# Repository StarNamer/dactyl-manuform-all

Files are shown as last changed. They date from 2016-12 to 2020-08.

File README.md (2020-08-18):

<div align="center">

# Dactyl ManuForm Keyboard



This is a fork of the [Dactyl-ManuForm](https://github.com/tshort/dactyl-keyboard).  
The Dactyl-Manuform is a fork of the [Dactyl](https://github.com/adereth/dactyl-keyboard) with the thumb cluster from [ManuForm](https://github.com/jeffgran/ManuForm).

</div>

## Differences to [carbonfet's](https://github.com/carbonfet/dactyl-manuform) dactyl-manuform
This version is adapted to my preferences and requirements. As such, there are a number of changes made to the root projects; the keyboard is still customizable, but changing the variables/parameters may require code changes as well.  
Changes to root project:

- Inclusion of [crystalhand's](https://github.com/crystalhand/dactyl-keyboard) wrist-rest
- All 1.0u keys (most ortho kits should provide all caps required for this build)
- Default manuform thumb cluster, but moved out a little bit (I have big hands and want my thumb to rest on the first thumb key)
- Some fixes to the generated bottom plate, which was faulty if extra bottom row is used (which I do)
- Usage of Bossard BN1936 brass inserts (M3) for screws
- Screw nubs moved inside the case

## Future changes (planned)

- Removal of controller board / TRRS jack holder breakout and putting of USB-C jack instead
- Development of my own controller board, QMK (and maybe VIA) programmable
- (Hopefully) Usage of BLE (as two separate keyboards) so no connection between the halves required
- (Alternatively) Usage of higher-quality 5-pin jack (no TRRS or audio jacks)

## Generate OpenSCAD and STL models

* Run `lein generate` or `lein auto generate`
* This will regenerate the `things/*.scad` files
* Use OpenSCAD to open a `.scad` file.
* Make changes to design, repeat `load-file`, OpenSCAD will watch for changes and rerender.
* When done, use OpenSCAD to export STL files

## License

Copyright © 2015-2020 Matthew Adereth, Tom Short and Leo Lou, Andreas Hauser

The source code for generating the models is distributed under the [GNU AFFERO GENERAL PUBLIC LICENSE Version 3](LICENSE).

The generated models are distributed under the [Creative Commons Attribution-ShareAlike 4.0 International (CC BY-SA 4.0)](LICENSE-models).

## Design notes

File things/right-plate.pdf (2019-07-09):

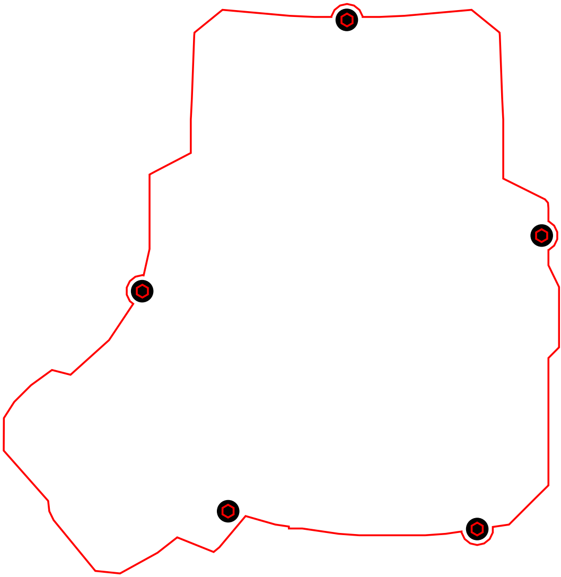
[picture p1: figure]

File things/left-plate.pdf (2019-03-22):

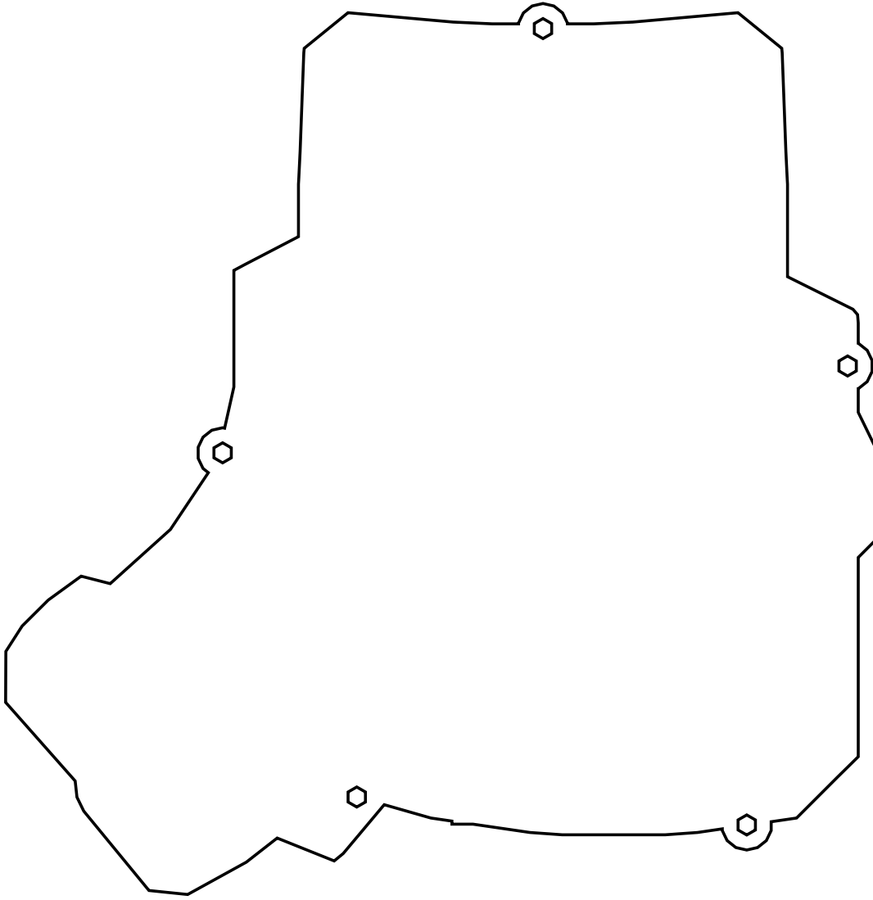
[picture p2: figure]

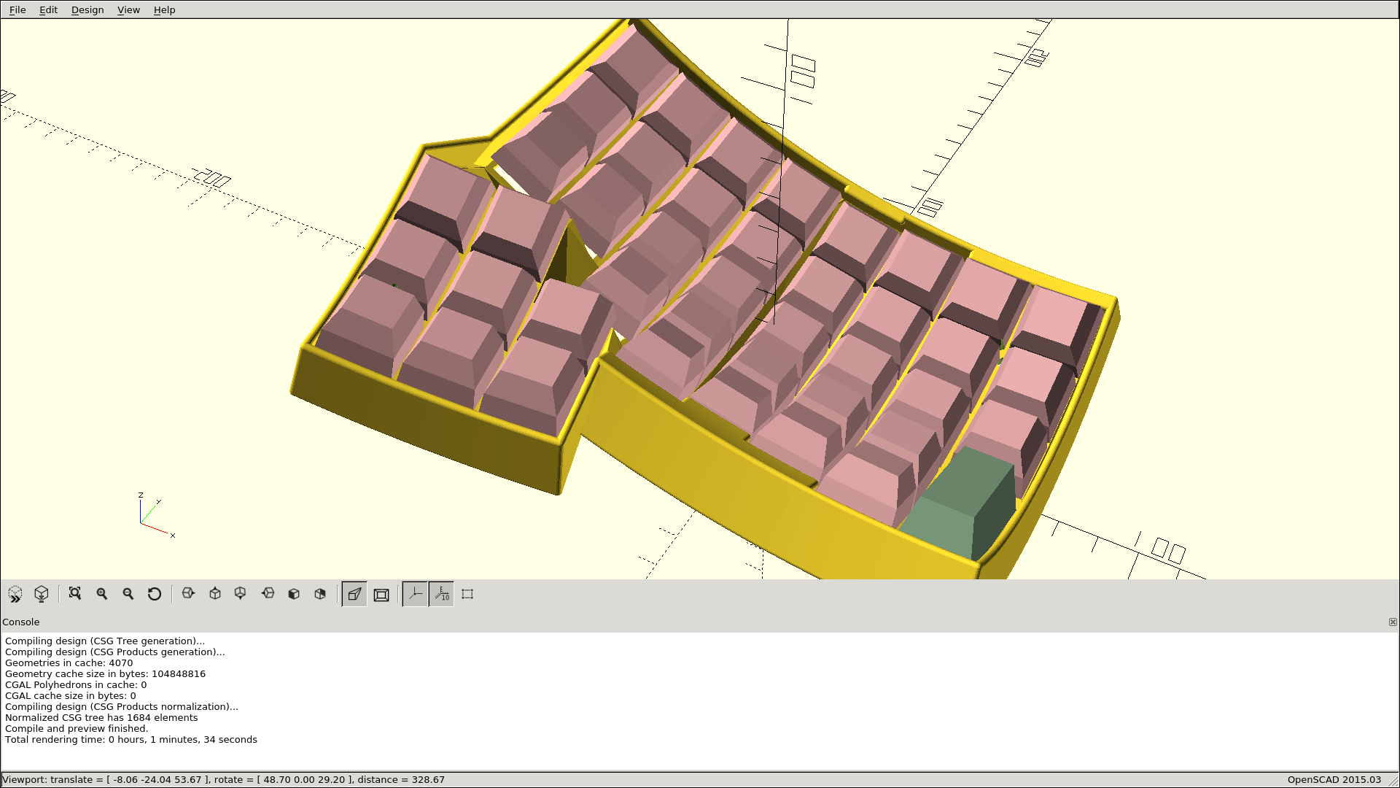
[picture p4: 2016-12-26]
resources/octadactyl.png

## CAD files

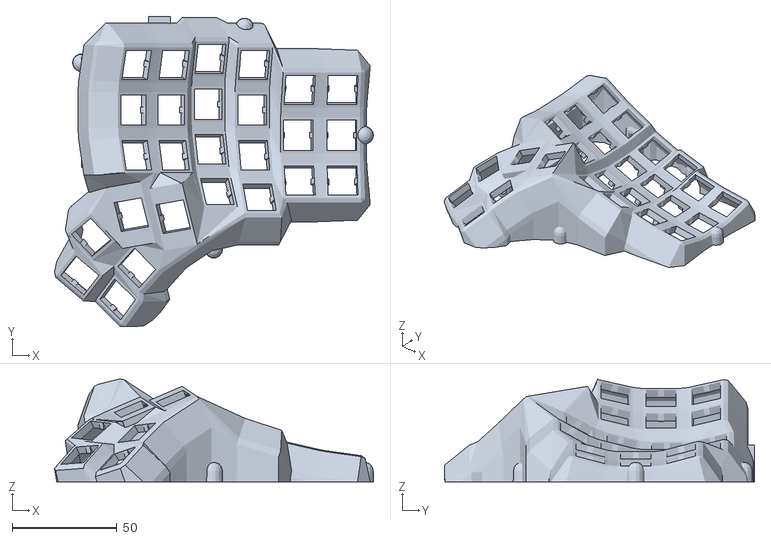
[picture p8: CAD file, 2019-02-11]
right.stl
152.3 x 148.0 x 49.2

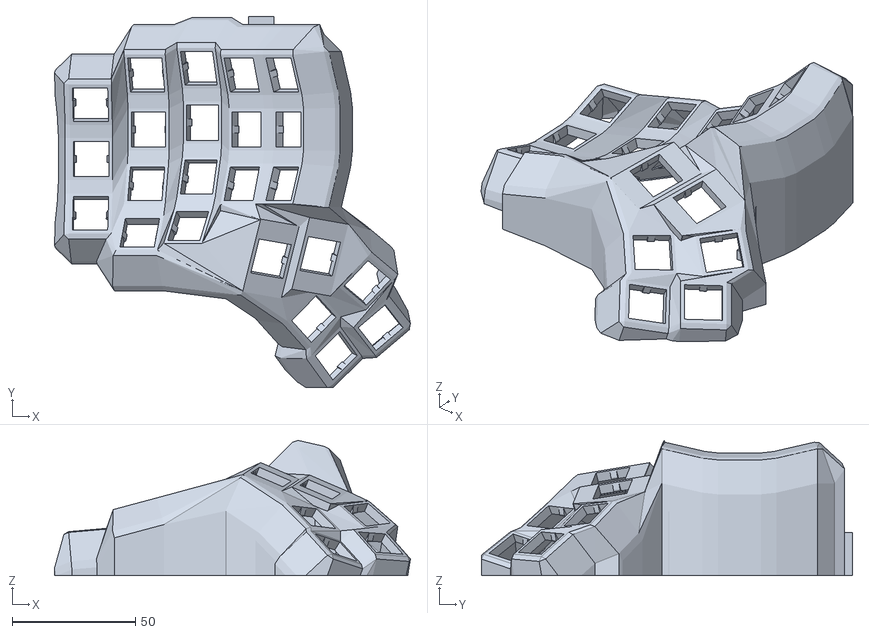
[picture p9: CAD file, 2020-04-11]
things/left.stl
144.7 x 150.9 x 55.0

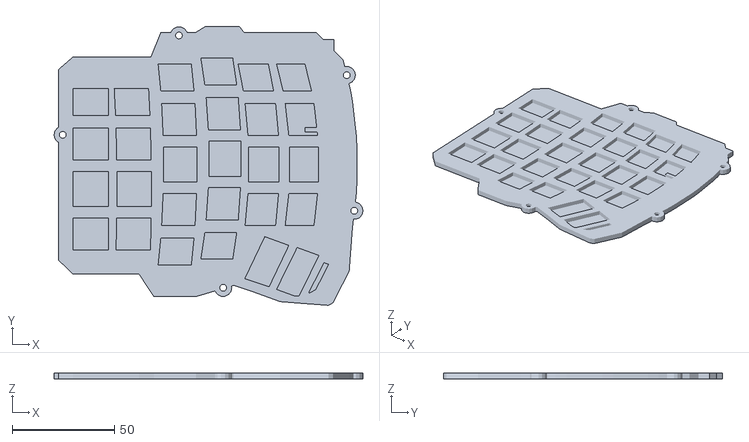
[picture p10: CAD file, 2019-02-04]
things/left-plate.stl
150.8 x 136.0 x 3.00

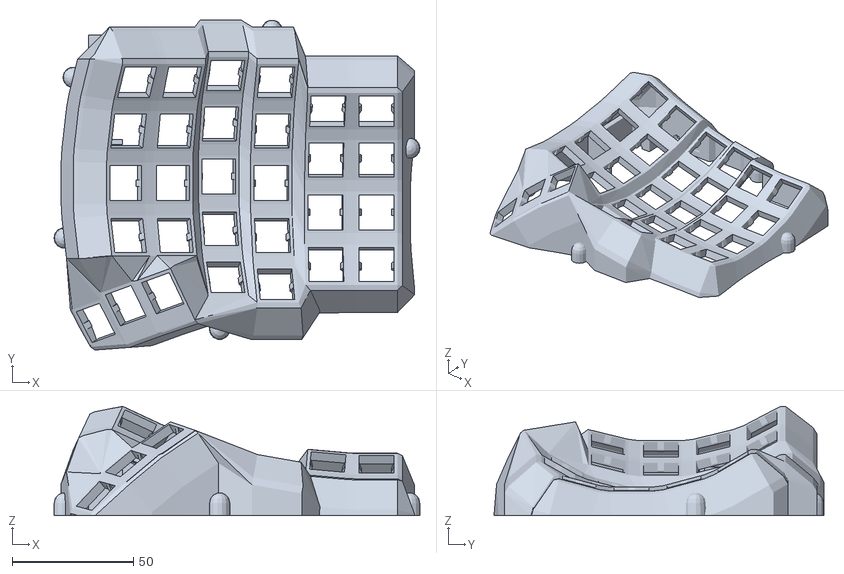
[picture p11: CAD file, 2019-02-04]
things/right(repaired).stl
150.8 x 136.0 x 45.1

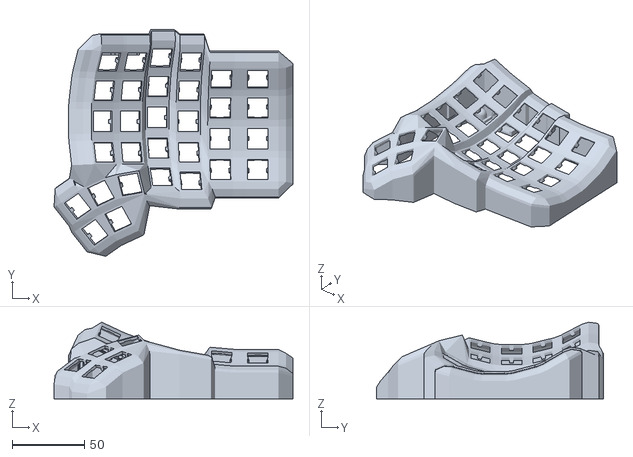
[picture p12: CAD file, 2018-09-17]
things/right.scad.stl
165.8 x 157.2 x 53.2

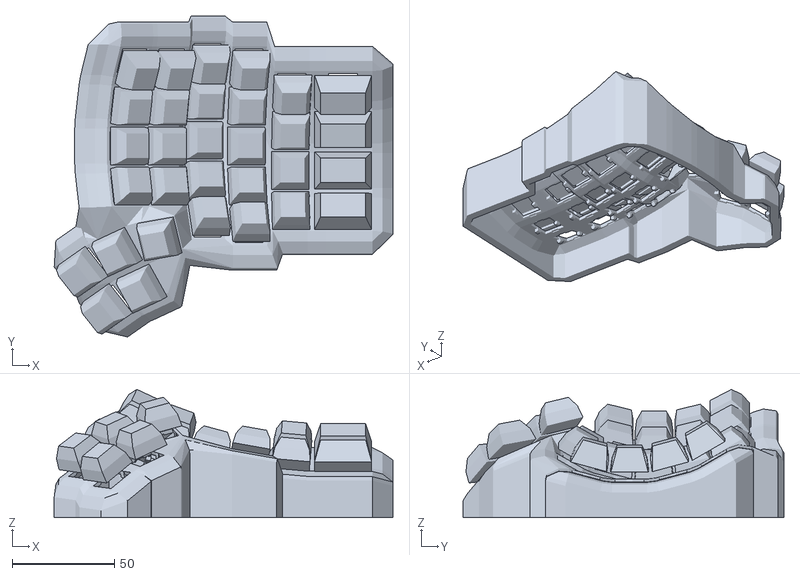
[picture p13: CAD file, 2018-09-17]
things/right-test.scad.stl
165.8 x 157.2 x 62.8

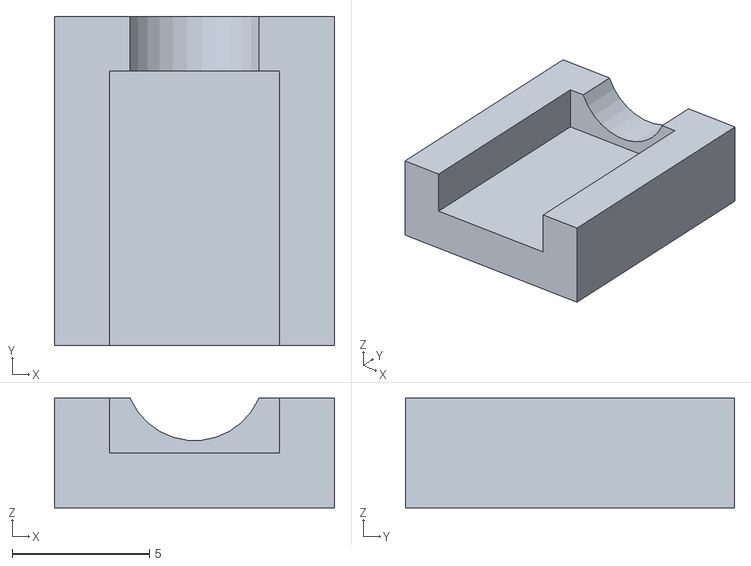
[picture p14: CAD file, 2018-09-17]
things/test.scad.stl
10.2 x 12.0 x 4.00

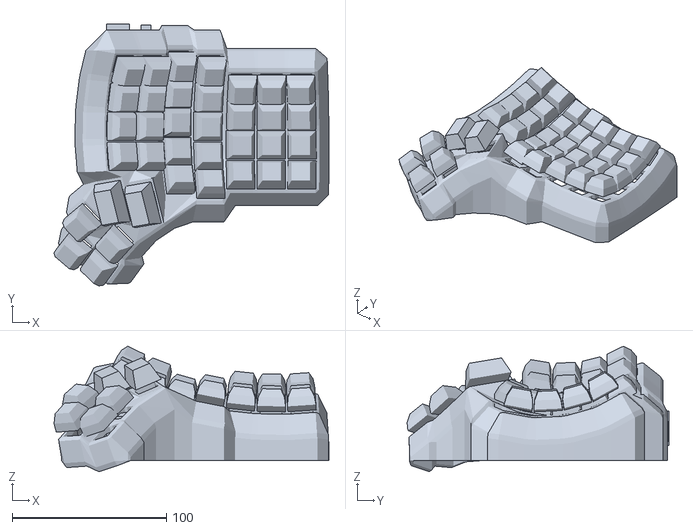
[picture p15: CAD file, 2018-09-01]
things/right-test.stl
178.4 x 169.9 x 81.5

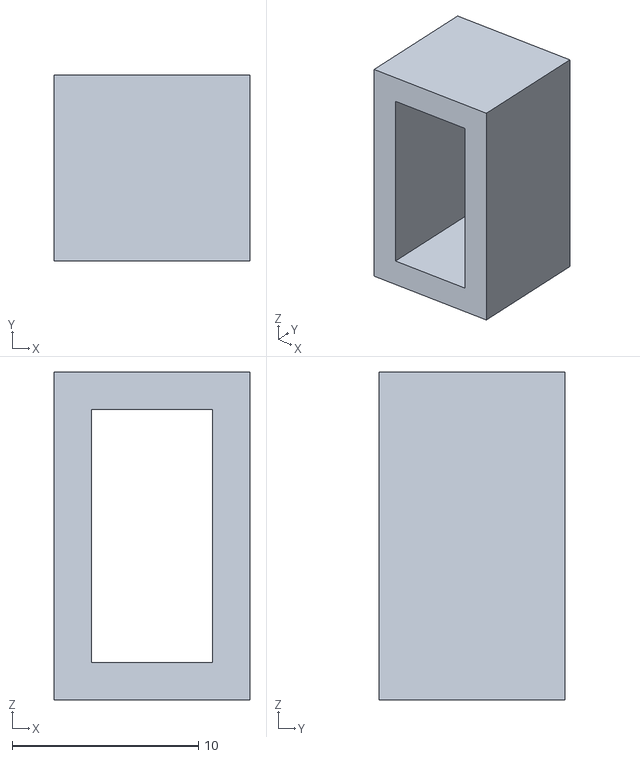
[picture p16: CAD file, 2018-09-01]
things/test.stl
10.5 x 10.00 x 17.6

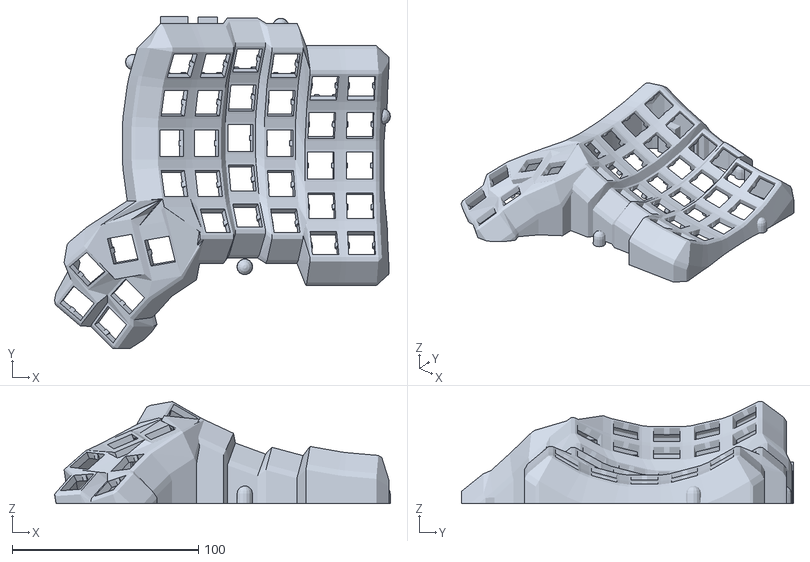
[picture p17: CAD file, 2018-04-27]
things/right-ergolike.stl
180.4 x 178.5 x 54.8

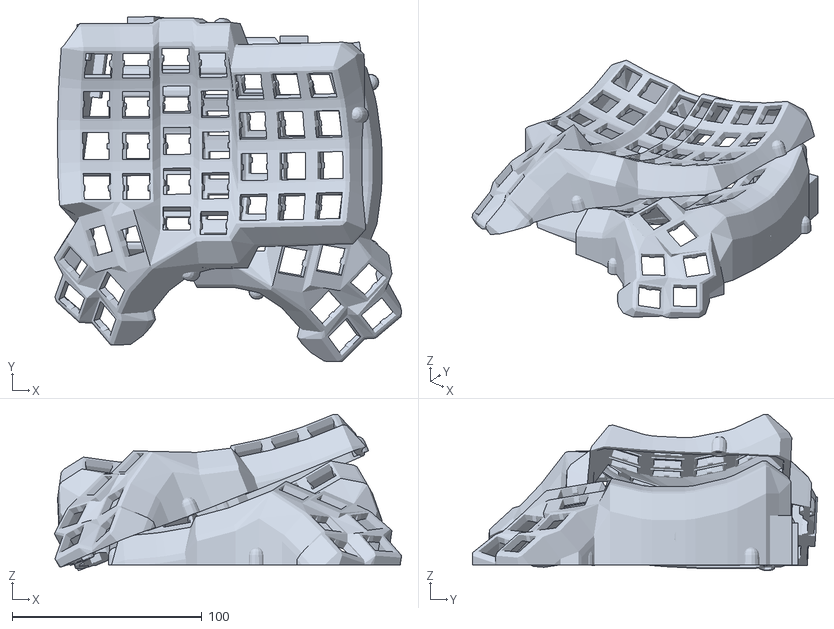
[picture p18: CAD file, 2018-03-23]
things/right-left.stl
182.9 x 181.6 x 82.3

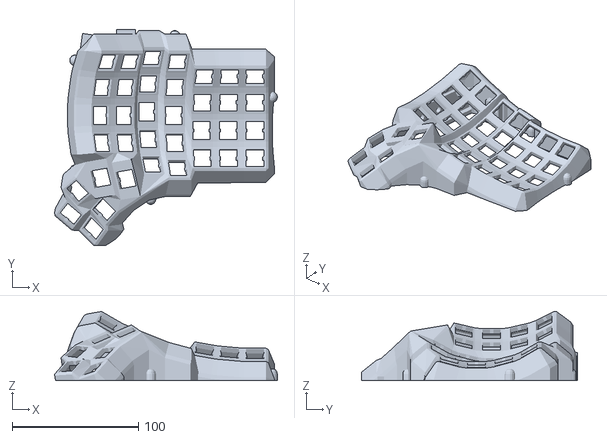
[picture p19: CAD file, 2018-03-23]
things/right-5x7.stl
176.8 x 171.5 x 54.8

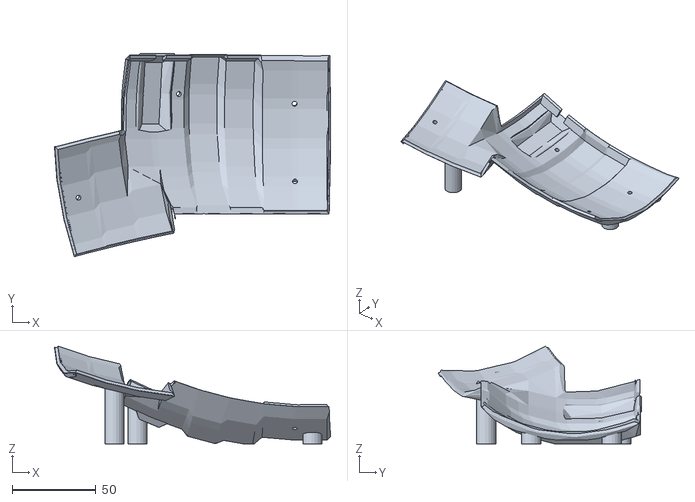
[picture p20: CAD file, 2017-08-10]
things/lightcycle-bottom-right.stl
164.7 x 121.4 x 58.4

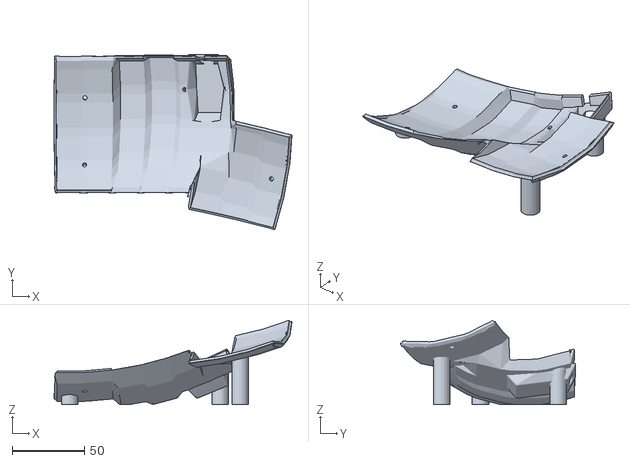
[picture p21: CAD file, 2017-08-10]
things/lightcycle-bottom-left.stl
164.7 x 121.4 x 58.4

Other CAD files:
left.stl
things/right.stl
things/right-plate.stl
things/left.scad.stl
things/alps-holes.scad
things/dactyl-bottom-left.scad
things/dactyl-bottom-right.scad
things/dactyl-rest-left.scad
things/dactyl-rest-right.scad
things/left-plate.dxf
things/left-plate.scad
things/left.scad
things/right-plate-laser.scad
things/right-plate.dxf
things/right-plate.scad
things/right-test.scad
things/right.scad
things/switch-hole.scad
things/test.scad

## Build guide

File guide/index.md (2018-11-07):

# How to Make a Dactyl Manuform Keyboard

Dactyl Manuform keyboard is a split-hand ergonomic keyboard. It isn't a commerial production so you have to make by yourself. 

This guide gives an overview to beginners who want to make a Dactyl Manuform keyboard. It links to websites with further information.

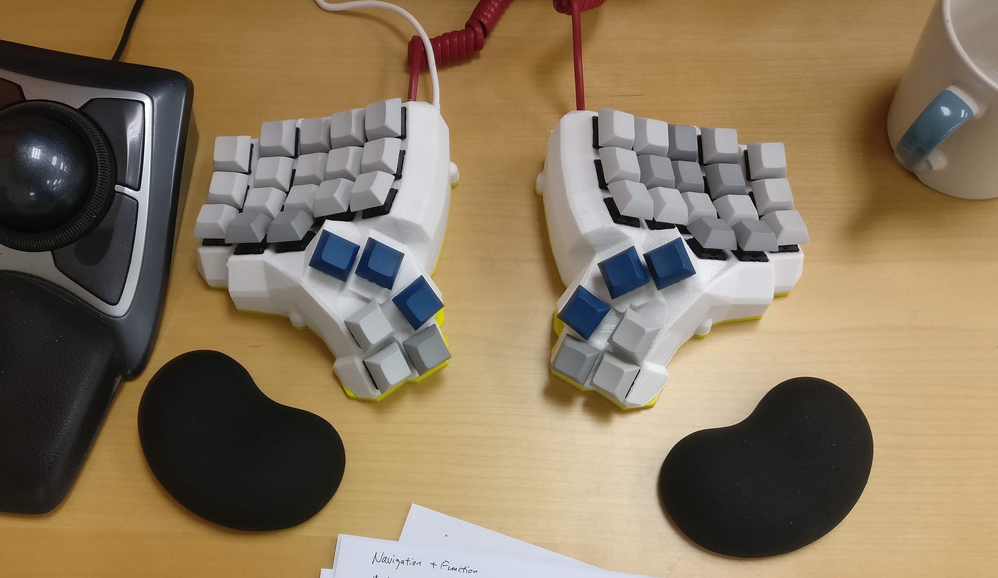
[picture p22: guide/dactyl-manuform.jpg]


## Materials

| Material | Number | | Remark |
| --- | --- | --- | --- |
| Arduino Pro Micro | 2 | | |
| Main body | left & right | | 3D printed |
| RJ9 cable | 1 | | Telephone handset cable |
| RJ9 connector | 2 | | Female connector. |
| Key switch | N | | Cherry MX |
| Keycap | N | | DSA or SA row 3. Four of them are 1.5U, but I use 1U as well. |
| 1N4148 diode | N | | |
| 10k resistor | 2 | optional | To tell left/right hand |
| Magnet wire or copper tape | | | To wire switches in column. |
| Bottom plate | left & right | optional | 3D printed |
| M3 flat head screw, 4~6mm  | 10 | optional | If you need to mount the bottom plate. |
| M3 heat set inserts, 4mm | 10 | optional | If you need to mount the bottom plate. |
| Tact switch, 6*6mm | 2 | optional | Reset button. Some manufactory's Pro Micro requires double reset to flash firmware. |

_N = number of keys_

I couldn't find a merchant on Ali Taobao who sells RJ9 female connector. Finally I got them from an old telephone. You can connect two parts with any cable with at least 3 wires.

## 3D Printing

The origin Dactyl-ManuForm keyboard project is [tshort/dactyl-keyboard](https://github.com/tshort/dactyl-keyboard). There are a lot of forks and some of them contain improvements or changes. You may need to take some time to choose which one is best fit for you.

Here listed some of the forks with changes:

- https://github.com/aleung/dactyl-manuform-keyboard - My fork // TODO: describe what's changed
- https://github.com/FSund/dactyl-manuform-keyboard
- https://github.com/l4u/dactyl-manuform-mini-keyboard

### Generate 3D Model

The model of Dactyl Manuform keyboard main body is written in Clojure programming language. To generate the STL file to send to print, you need below procedure:

```
Clojure source code --[Clojure]--> OpenSCAD source code --[OpenSCAD]--> STL
```

There is guide on the GitHub project about how to do it. But to a non-developer it might be still not easy to set up a Clojure development environment and run the program. You can download pregenerated STL file from [Thingiverse](https://www.thingiverse.com/) (search "manuform") or from `things` folder in GitHub projects, but then you lose the possibility to customise the model.

I found that the STL files generated by OpenSCAD are corrupted. But it can be repaired easily by auto repair function in [Netfabb Basic](https://github.com/3DprintFIT/netfabb-basic-download/releases).

I printed it in PLA with 0.2mm layer height. Each part took about 8 hours to print.

### Split Print

The print .... // TODO

## Circuit Wiring

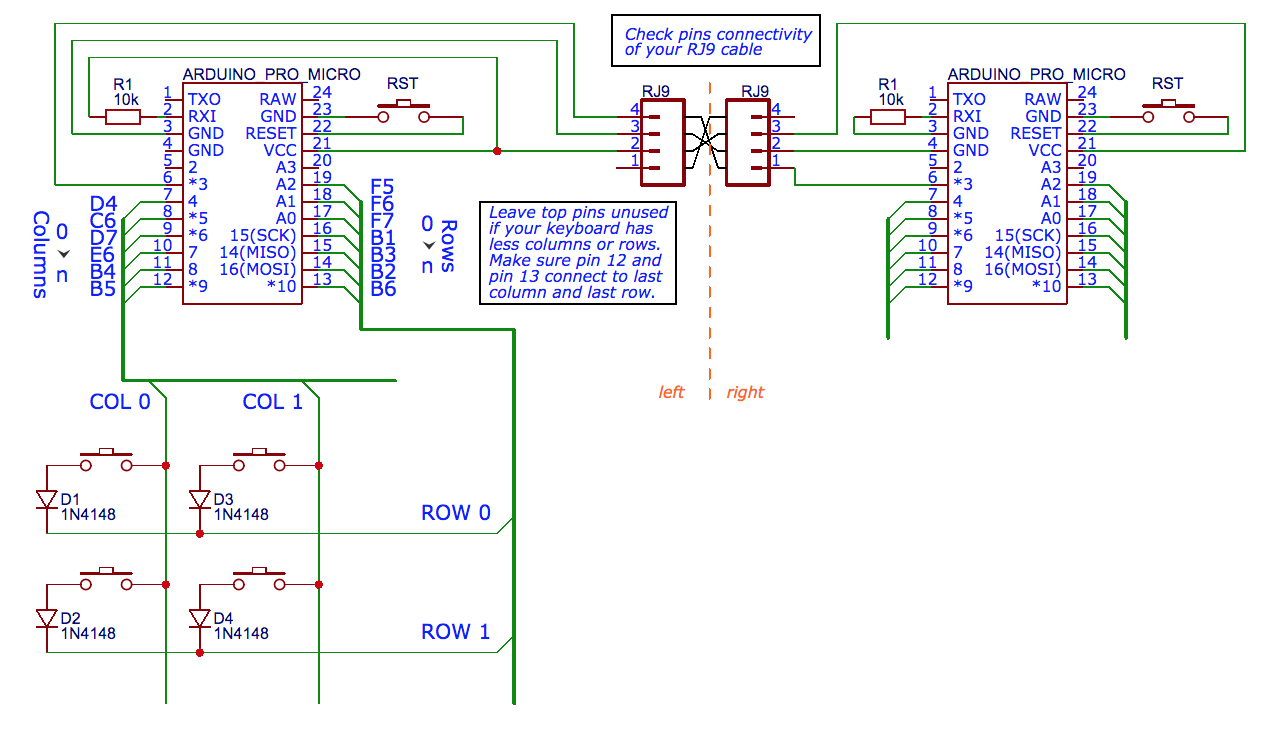
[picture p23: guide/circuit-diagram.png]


Note that a telephone handset cable has leads that are reversed, so take this into account when connecting these leads to the controller.

There is a 10k resistor (R1) connects to RXI pin (which is AVR pin D2). On left hand it pulls up to VCC and on right hand it pulls down to GND to tell firmware which hand it is. It's optional: if the RXI pin isn't connected to anything then you can config firmware to determine left/right by whether has USB cable plugged (having USB connection is master). It's described in Firmware Config section below.

There is no standard way to wire the matrix of keys. You can decide how to connect them into rows and columns, as long as you adjust the layout definition accordingly in firmware.

According to QMK firmware convention, rows are numbered from top to bottom and columns are numbered from left to right. 

Below is a solution to wire a 5x6 keyboard. It's compatible with QMK firmware v0.6.156 (which is the latest version at the time I'm writing this).

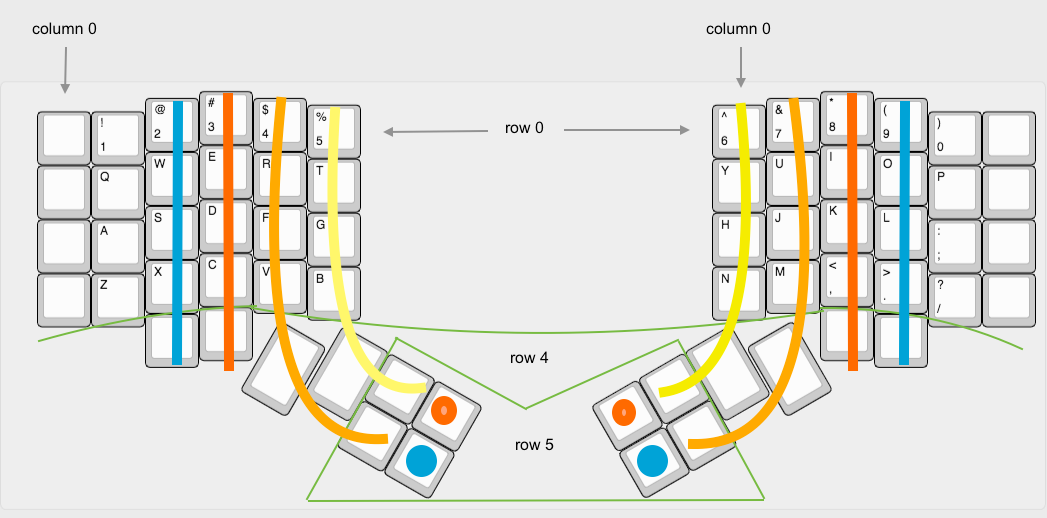
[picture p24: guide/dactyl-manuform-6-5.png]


_Note: the first diagram of 4x5 wiring in tshort's origin project (and in a lot of forks) is not recommended. It requires more complicated layout configuration in QMK firmware because left and right parts don't use the same pinouts._

To wire the columns, you may use magnet wire or copper tape. To wire the row just use the diods legs as wires connecting each one. QMK has a [hand-wiring guide](https://docs.qmk.fm/#/hand_wire) that explains quite well.

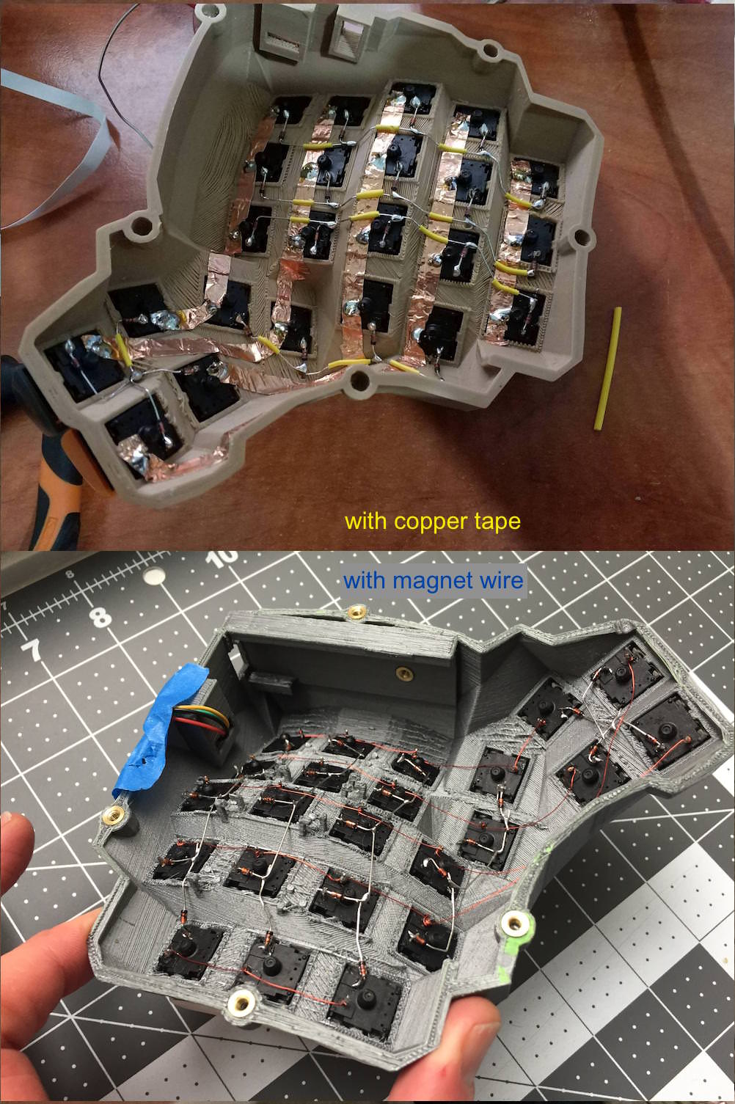
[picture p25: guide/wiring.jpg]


## Firmware

The latest [QMK firmware](https://github.com/qmk/qmk_firmware) already has built-in split keyboard support. So right now it's nothing special to setup a Dactyl Manuform in QMK.

There is predefined Dactyl Manuform keyboard in QMK firmware source code, in directory [`keyboards/handwired/dactyl_manuform/`](https://github.com/qmk/qmk_firmware/tree/master/keyboards/handwired/dactyl_manuform), with several models (4x5, 4x6, 5x6...). But rather than directly use it, I strongly suggest you to choose one model as baseline and copy as another folder, for example `mine`, then make your modification. It's because the firmware config is highly depends on how the keys wired and there is no standard way to wire. At the time I'm writing, the different predefined models don't follow the same way of wiring.

What's more, when you have your own copy in another folder, you can safely merge latest QMK firmware to get update in QMK core, without fearing your keyboard config got changed by others' commit.

In below example I assume the folder is `keyboards/handwired/dactyl_manuform/mine` and it's a 4x5 keyboard.

### Config

The first thing you need to define is how the Pro Micro pinouts connect to key matrix. It's set in `mine/config.h`:

```c
#pragma once
#include "config_common.h"
#define PRODUCT         Dactyl-Manuform (4x5)  // The name of the keyboard shown in OS

#define MATRIX_ROWS 10                         // left rows + right rows
#define MATRIX_COLS 5
#define MATRIX_ROW_PINS { F7, B1, B3, B2, B6 } // 5 rows each size
#define MATRIX_COL_PINS { C6, D7, E6, B4, B5 } // 5 columns. 
                        // col_0 connects to pin C6; col_1 connects to pin D7; ...

#define USE_SERIAL

// How to determine left/right hand. Choose one:
#define SPLIT_HAND_PIN D2  // must have 10k resistor connect to RXI pin
// #define MASTER_LEFT
// #define MASTER_RIGHT
```

Note that the pins aren't Pro Micro pins, but AVR microcontroller pins. I've marked the mapping AVR pins beside Pro Micro pins in the circuit diagram above.

By giving `MATRIX_ROW_PINS` and `MATRIX_COL_PINS`, you define the key matrix by rows and columns wiring in cuicuit. 

The next step is to define a mapping to each keys on the keyboard. It's inside `mine/keyboard.h` (you can change `keyboard` to any name, so long as all existences are changed):

```c
#pragma once
#include "quantum.h"

#define LAYOUT( \
    L00, L01, L02, L03, L04,                     R00, R01, R02, R03, R04, \
    L10, L11, L12, L13, L14,                     R10, R11, R12, R13, R14, \
    L20, L21, L22, L23, L24,                     R20, R21, R22, R23, R24, \
         L31, L32,                                         R32, R33,      \
                   L33, L34,                     R30, R31,                \
                           L44, L42,     R42, R40,                        \
                           L43, L41,     R43, R41                         \
	) \
    { \
		{ L00, L01, L02, L03, L04 },   \
		{ L10, L11, L12, L13, L14 },   \
		{ L20, L21, L22, L23, L24 },   \
		{ KC_NO, L31, L32, L33, L34 }, \
		{ KC_NO, L41, L42, L43, L44 }, \
                                       \
		{ R00, R01, R02, R03, R04 },   \
		{ R10, R11, R12, R13, R14 },   \
		{ R20, R21, R22, R23, R24 },   \
		{ R30, R31, R32, R33, KC_NO }, \
		{ R40, R41, R42, R43, KC_NO }  \
    }
```

You need to carefully check and update the `LAYOUT` macro in this file. There are several lines but actually  what you need to change are in two parts: _physical_keyboard_layout_ and _key_matrix_in_circuit_.

```
#define LAYOUT( <physical_keyboard_layout> ) { <key_matrix_in_circuit> }
```

Let's first see the _key_matrix_in_circuit_ section, each line is a row. First rows are left hand part from row 0 to row 4, and last rows are right hand part from row 0 to row 4 as well. The rows and columns connect to the pins defined in `MATRIX_ROW_PINS` and `MATRIX_COL_PINS` in `mine/config.h`. For the key switch wiring on a row and a column, give it a name by the row number and column number. See below picture as example. If there is no key switch connects between a row and a column, mark it with `KC_NO`.

In _physical_keyboard_layout_ section you put the keys into a shape which is similar to the keyboard physical layout. The spaces and new lines are just for human being to easily read. They mean nothing to the compiler. Actually they're just a list of identifiers.

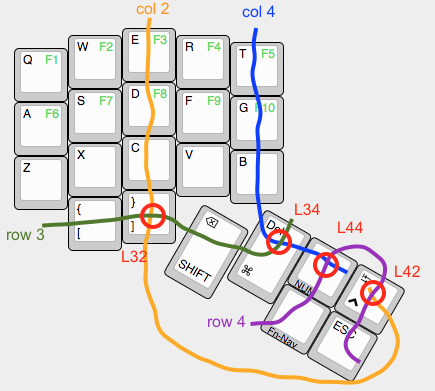
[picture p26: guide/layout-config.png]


It's easy to make mistake on the thumb keys. Double check them.

For the simpliest case there is nothing need to be configured inside `mine/keyboard.c`:

```c
#include "keyboard.h"   // remember to change here if you've renamed 'keyboard'

void matrix_init_kb(void) {
	matrix_init_user();
};
```

Now you're done the configurations which is related to how your keyboard is made. 

### Keymap

The keymap defines when a key or keys combination is pressed, what keycode is sent to computer.

QMK firmware has rich features for keymaps. You should read its document beginning from this one: https://docs.qmk.fm/#/keymap

I use the default keymap of my keyboard as example. The code can be found on [GitHub](https://github.com/aleung/qmk_firmware/tree/my_dactyl_manuform/keyboards/handwired/dactyl_manuform/mine/keymaps/default). It's in three layers: base layer for alphabets, a function keys and navigation keys layer and a numbers and punctuation layer. This picture shows partial of the keymaps:

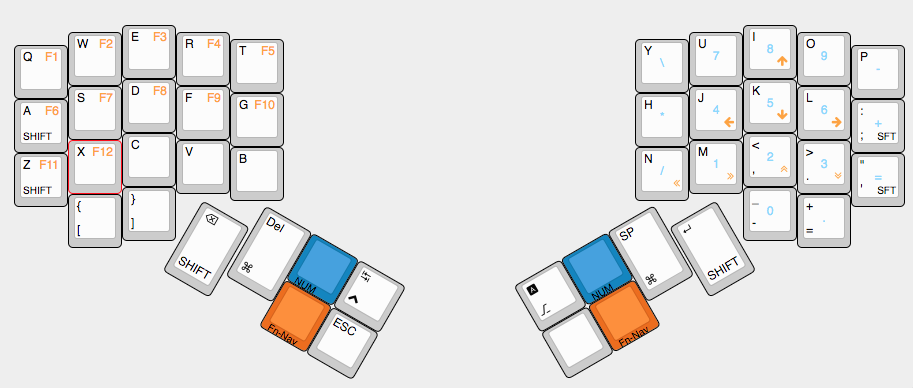
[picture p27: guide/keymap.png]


Below is the base layer config of my keyboard. The `LAYOUT` macro defined in `mine/keyboard.h` is used here to assign keycode to each key. It's reasonable to format it alike real keyboard -- intuitive to view. For the key which has no keycode assigned, which mean it's unused, set a placeholder `____` inside.

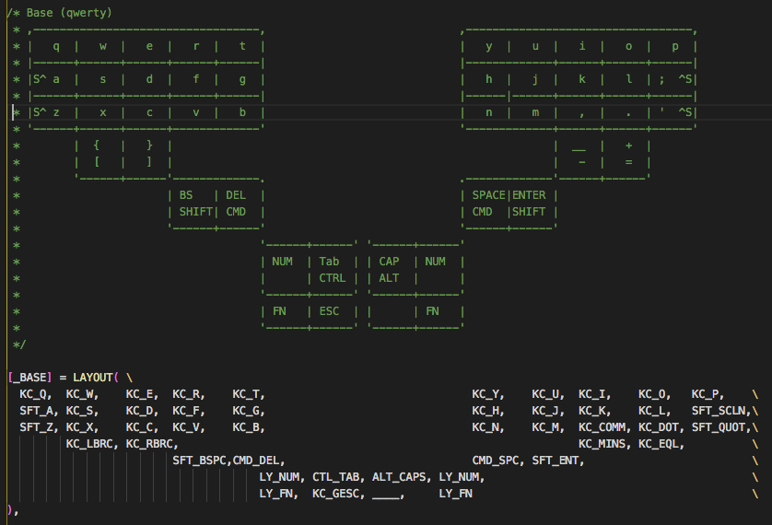
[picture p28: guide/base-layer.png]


### Compile

The easy way to compile the firmware is using docker. It saves the time to setup the build environment.

Run below command under the root directory of `qmk-firmware` project:

```sh
docker run -e keyboard=handwired/dactyl_manuform/mine -e keymap=default --rm -v $('pwd'):/qmk:rw acette/qmk_firmware
```

Of cause, you have to already have Docker installed in your system.

If everything works fine, a `.hex` file is generated.

### Flashing

Last step is to use [QMK Toolbox](https://github.com/qmk/qmk_toolbox) to flash the firmware into the keyboard.

Connect the keyboard to computer with USB cable and wait for a few seconds. Open QMK Toolbox, select the hex file to be flashed. When everything is ready, double click the reset button on keyboard and the Pro Micro will go into bootloader mode for 8 seconds. You must start flashing within this period. 

The left hand part and right hand part both need to be flashed.

All done!

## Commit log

2016-08-13 Changed bottom case to be easier to print on FDM printers
    [dactyl-bottom-left.scad, dactyl-bottom-left.stl, dactyl-bottom-right.scad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]
2016-08-15 Fix issue with back wall not fitting properly
    [dactyl-bottom-left.scad, dactyl-bottom-left.stl, dactyl-bottom-right.scad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]
2016-11-03 New version: teensy on both side
2016-12-03 Fix back-wall hull
2016-12-11 - Switch middle double key on thumb cluster for two single keys - Add key above the right double key - Fix web connectors
2016-12-26 - Exchange two lower right most single keys for a vertical double. - Make corresponding changes to hull and wall. - Move out "thumb-*" definitions to global scope and rename to "long-*"
2016-12-26 Move screw hole a bit to the left
2017-08-10 1. use MX as default; 2.add one more screw hole; 3.move teensy to left hand and remove teensy support
    [dactyl-bottom-left-with-teensy.stl, dactyl-bottom-left.stl, dactyl-bottom-right.stl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]
2017-11-03 Move covers to avoid interference with screw holes
2017-11-09 Fix front wall of bottom case
2017-11-12 Brush up thumb bottom plate
2018-03-16 remove side nib for kailh speed switches
2018-03-16 add things
    [left-4x5.stl, left-4x6.stl, left-5x6.stl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]
2018-03-20 Add another screw insert
2018-03-20 Adjust screw inserts
2018-03-20 Add CAD files.
    [left-4x5.stl, left-4x6.stl, left-6x6.stl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]
2018-03-20 Fix shapeways warn
    [fix-thick-test.stl, left-5x7.stl, right-5x7.stl]
2018-03-21 remove wire-post
    [left-5x6-fixed.stl, right-5x7.stl]
2018-04-26 adding 5th row buttons more like ergodox
2018-04-26 connectors on thumb clusters line up now
2018-04-27 close to original thumb spacing and tenting
    [right-ergolike.stl]
2018-07-08 comment with masks for printing
2018-07-09 fix thumb walls to main case, remove nubs, small geometry on usb holder
2018-09-01 rev2 printed
    [left-plate.dxf, left-plate.scad, left-plate.stl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]
2018-09-04 add generated scad files
    [left.scad, right-plate.scad, right-test.scad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]
2018-09-17 add stl files
    [left-4x5.stl, left-4x6.stl, left-5x6.stl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]
2018-09-25 add: kailh hotswap socket plate
    when use this, uncomment/comment `(def single-plate ...)`
2018-09-25 mod: top.scad(kailh socket)
2018-10-13 add define, kailh socket hole for hako switch
2018-10-19 Add key hole side nub
2018-10-19 Add arduino holder, remove teensy-holder
2018-10-20 Generate infilled plate
2018-10-24 Improve arduino holder
2018-10-24 Add a hole to mount reset button
2018-10-25 Improve arduino holder and reset button holder
2018-10-25 Add holes for flat head screws on bottom plate
2019-01-27 Remove unused files
    [left-4x5.stl, left-4x6.stl, left-5x6.stl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]
2019-01-28 Replace RJ9 connector space with a wire hole; move USB hole position a bit.
2019-02-04 Increase thumb area slope and move a bit away from index finger
2019-02-04 Add pictures and STL files
    [left-plate.stl, right(repaired).stl, right-plate.stl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]
2019-02-10 Added WIP hole for a reset button
2019-02-11 Removed reset switch, changed RJ9 connector to a TRRS jack, as it's easier to source
2019-02-11 Added STL files for both halves
    [left.stl, right.stl]
2019-02-11 Added printing company note
2019-02-11 Updated tenting angle and added a column
    [left.stl, right.stl]
2019-03-22 Added plate schematics
2019-08-05 disable everything except separate finger and thumb cluster plates
2019-08-15 Socket v3
2019-08-15 Socket v4
2019-08-15 Socket v5, finally working as it should!
2019-08-16 Switch hole version 6
2019-08-16 Implemented parameterized support for different switch types.
2019-10-16 Basic trackpoint bed done.
2019-11-28 New trackpoint plate with holes
2019-11-28 Trackpoint nut holes fine tuning
2019-11-28 Trackpoint holes tuning
2019-12-21 Switch fitting changed
2020-03-19 Cable hole added
2020-04-11 more curve, lower deck, thumbs out
    [left.stl, right.stl]
2020-05-01 reduce key hole nub size slightly
2020-08-11 Add usb holes, tweak the thumb cluster a bit, add a bit more spacing between the keys.
2020-08-18 Lower the board, revert the extra set of buttons on the pinky rows, and adjust the usb cutouts.
2020-08-18 Add docker-compose.yml, main function for lein run
    [alps-holes.scad, switch-hole.scad]
2020-08-18 add naive implementation
    [alps-holes.scad]
2020-08-18 Inital version after fork
    [controller holder (elite-c).stl, controller holder.stl, left.scad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]
